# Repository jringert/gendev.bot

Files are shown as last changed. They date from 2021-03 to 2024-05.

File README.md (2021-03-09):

# gendev.bot
Materials for [small rover robot](gendev.bot.esp8266/) used in Generative Development module:
* ESP8266-based [rover robot](gendev.bot.esp8266/) with list of materials and Arduino IDE code
* [Java code running a HTTP server](gendev.bot.runner/) responding base on different engines, e.g., generated code from an UMPLE state machine or a synthezied Spectra controller

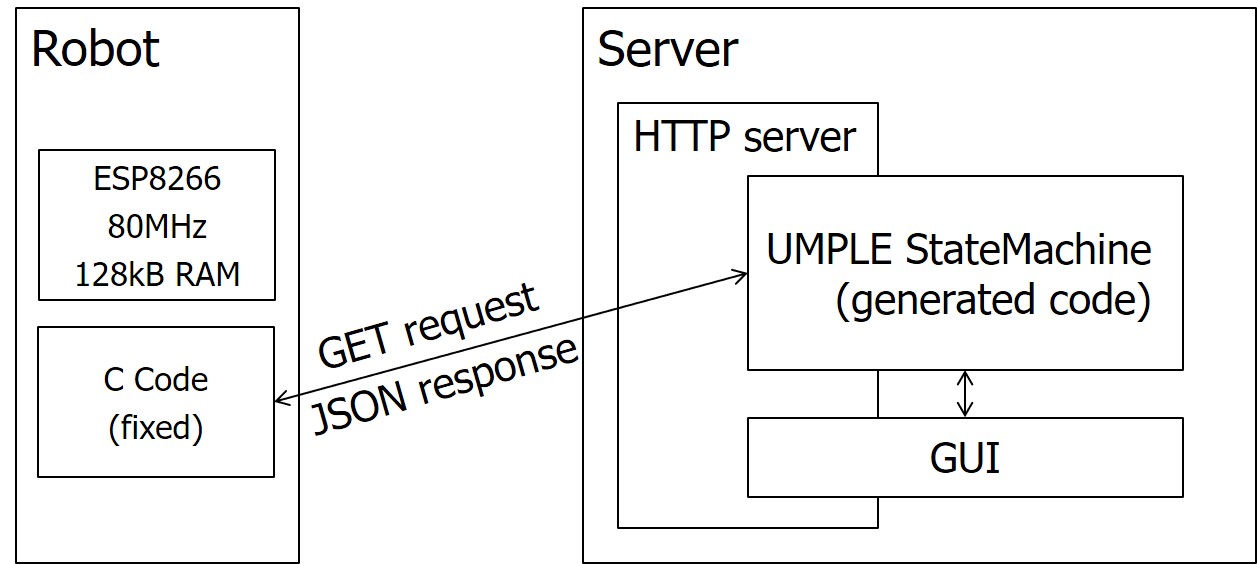
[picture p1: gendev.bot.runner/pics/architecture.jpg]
schematic system overview


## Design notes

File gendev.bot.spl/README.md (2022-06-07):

# gendev.bot.spl
This folder contains variants of the GenDevBot implementation.

* ESP8266-based [rover robot](gendev.bot.esp8266.full/)
* ESP32-based
  * [full featured](gendev.bot.esp32.full/)
  * [full featured but without WiFi manager](gendev.bot.esp32.lean/)
  * [basic USS driving](gendev.bot.esp32.drive/)
  * [basic USS driving with capacitive emergency stop](gendev.bot.esp32.driveEmg/)

An incomplete version of an `#ifdef`-based Software Product Line is contained in [gendev.bot.esp32.all](gendev.bot.esp32.all/). This initial version has been developed [in this video](https://www.youtube.com/watch?v=XeSsomehpjg&list=PLGyeoukah9NYD35EgjpJ6ZT8KZO7JowTK&index=4).

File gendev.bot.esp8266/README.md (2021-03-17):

# gendev.bot.esp8266 Arduino IDE code
Code to flash on the NodeMCU compatible ESP8266.

Requires to install ESP8266 boards in Arduino IDE.
* Select `File > Preferences` under `Additional Boards Manager URLs` add `http://arduino.esp8266.com/stable/package_esp8266com_index.json`
* Select `Tools > Board: ... > Boards manager` type `esp8266` and click `install`

Some computers might require a USB driver to see the ESP8266 in Arduino IDE. See [these instructions](https://learn.sparkfun.com/tutorials/how-to-install-ch340-drivers/all).

Requires the following libraries.
* Select `Tools > Library Manager` and then find these libraries.
  * NewPing by Tim Eckel for ultra-sonic sensor (USS) https://bitbucket.org/teckel12/arduino-new-ping/wiki/Home
  * ArduinoJson by Benoit Blanchon for parsing JSON responses https://arduinojson.org
  * WifiManager by tzapu/tablatronix (a bit far down the list) https://github.com/tzapu/WiFiManager
  
## Functionality
* configures WiFi AP via HTTP
* reads distance using an USS
* sends a HTTP GET request http://host:8080/robot?distance=123
* reads JSON response with fields
  * rightM in {FWD, STP, BWD}
  * leftM in {FWD, STP, BWD}
* powers two or four motors via H-bridge

## Hardware
The links below are [Amazon.co.uk Associate](https://affiliate-program.amazon.co.uk) links. You can use [Amazon Prime Student](https://www.amazon.co.uk/gp/student/signup/info?tag=ringert-21) (free for the first 6 months) to get free one-day shipping.

* [Car with two motors and battery pack](https://amzn.to/3caJQyW) ca. 12GBP
* [ESP8266 as the main controller](https://amzn.to/3v7EAor) ca. 6GBP 
  * or buy 5 of them for 18GBP [5 x ESP8266](https://amzn.to/3emhXGN)
* [Cables with connectors](https://amzn.to/3rInr2J) ca. 7GBP
  * or buy any cheap cable if you are happy do to more soldering
* [L9110S H-bridge to drive motors](https://amzn.to/30t5zge) ca. 5GBP
  * or buy 6 of them for 8GBP [6 x L9110S H-bridge](https://amzn.to/3qvHqQG) (you only need one)
* [HC-SR04 Ultrasonic distance sensor](https://amzn.to/2PNbPNH) ca. 7GBP
  * or buy 5 of them for 10GBP [5 x HC-SR04 sensor](https://amzn.to/3ejJSqZ) (you only need one)
* [AA Batteries](https://amzn.to/38FKIuH) ca. 8GBP (you need 4 to 6)

You can also buy a kit and even save money, e.g., this [Arduino UNO robot](https://amzn.to/3rxuCdJ) for only 33GBP. The problem is that it doesn't have WiFi, but it should be easy to replace the Arduino UNO with an ESP8266 (see list above).

The materials can be bought much cheaper on [Aliexpress](https://aliexpress.com)  if you are willing to wait that long (shipping can take anywhere from a week to a month). You might 20 GBP instead of 40 GBP.

In any case you might need the following tools:
* a soldering iron (to connect the cables to the motors and maybe to the battery pack)
* a small screw driver to connect cables from the motors to the H-bridge
* (optional) a hot glue gun to secure all cables

## Build instructions

A [video of how to connect things](https://youtu.be/WTPfQyEEh8c) is avaiable.

The connections to PINs are documented in the code and shown here. Fritzing files are available in folder docs.
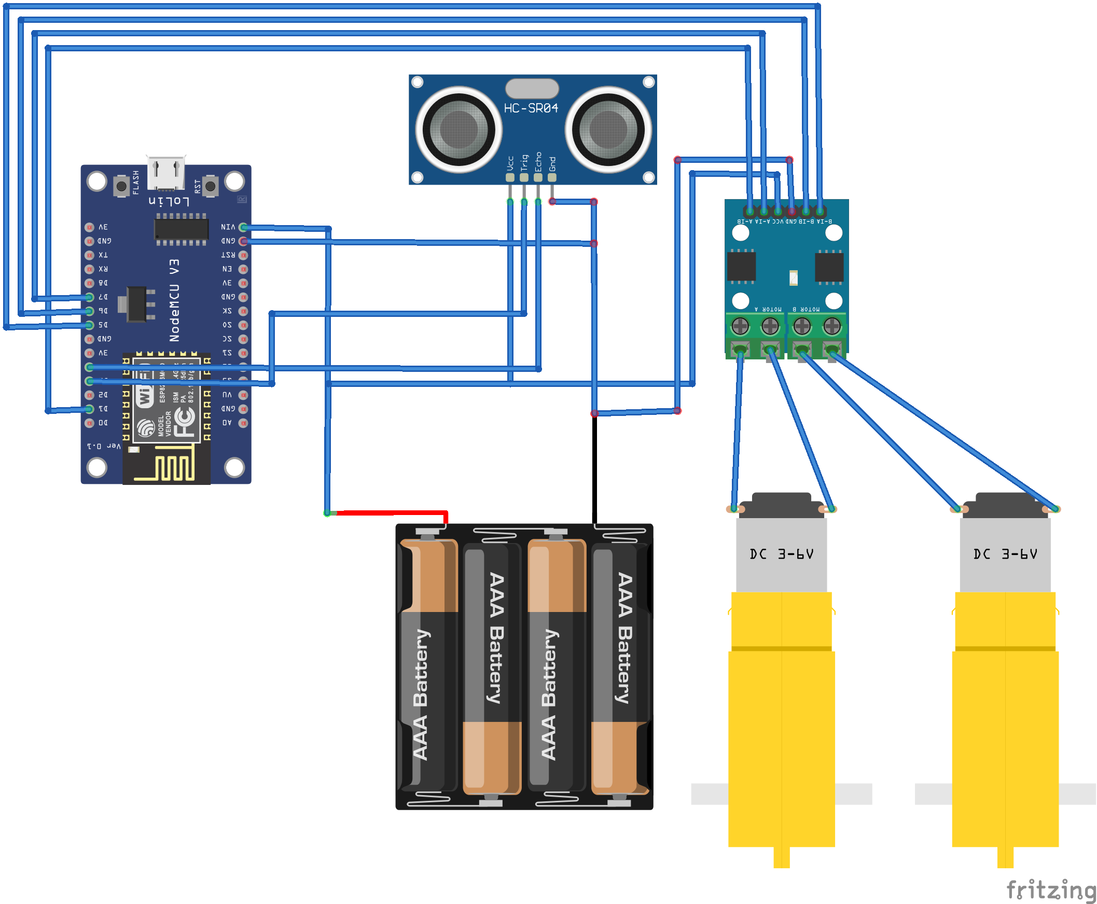
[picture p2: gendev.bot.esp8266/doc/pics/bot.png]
connections ignoring VCC/GND


## Code upload and first run

In the arduino code you have to configure the IP address of the computer that runs the Java program. This requires the ESP8266 and the computer to be on the same network (this is usually the case at home where you have a WiFi router). You might want to configure a fixed IP for the computer in your router settings. Alternatively you can create a mobile hotspot on your phone and connect the computer to it.

Enter the local network IP of the computer (something like 192.168.0.1337) in the line below (ca. line 88 in [gendev.bot.esp8266.ino](gendev.bot.esp8266.ino)). You will also have to enter this IP in the Java code running on the computer.
```c
if (http.begin(client, "192.168.0.1337", 8080, "/robot?distance=" + String(distance), false)) {
```

Once the code is uploaded to the ESP8266 it will create a WiFi network called `GendevBotAP`. Connect to this WiFi, e.g., with your phone or computer and let the ESP8266 scan for networks. Select your network and enter the password. The ESP8266 will then reboot and connect to that network. It will immediately try to talk to the computer running the Java server.

# Possible Hardware Extensions
An easy way to extend the robot is by adding more sesor and additional motors. The ESP8266 should still have a few free pins for that.

Another extension is to put a Raspberry Pi with a camera on the robot to have much more processing power onboard. In this case you can either try to replace the ESP8266 or simply connect it to the Raspberry Pi via WiFi (as in the above setting) or even USB. The Raspberry Pis are much cheaper on [The Pi Hut](https://thepihut.com/) than on Amazon:
* a [Raspberry Pi zero with WiFi](https://thepihut.com/products/raspberry-pi-zero-w) ca. 10GBP, or 
* a [Raspberry Pi 4B](https://thepihut.com/products/raspberry-pi-4-model-b?variant=20064052674622) between 34GBP (2GB RAM) and 74GBP (8GB RAM)
* there are tons of extensions with [cameras](https://thepihut.com/pages/search-results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) etc.

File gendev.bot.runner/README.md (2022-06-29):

# Eclipse project gendev.bot.runner
Project for executing some engine for generated code and making it available for the robot to connect to via HTTP.

Currently supported engines:
* UMPLE StateMaching code (examples included)
* Spectra synthesized controllers
* AspectJ aspects decorating a Java implementation

schematic system overview

## Project contents
* UMPLE StateMachines are in the root of folder src (to generate code from Eclipse)
* Spectra specifications are in the root folder (synthesize controllers from these)
* AspectJ aspects are in in package `gendev.bot.runner.aspectj`

## Plug-Ins
* UMPLE code generation requires the UMPLE plug-in available from `http://cruise.umple.org/org.cruise.umple.eclipse.plugin.update.site`
* Spectra synthesis requires the Spectra Tools plug-in available from `http://smlab.cs.tau.ac.il/syntech/spectra/tools/update/`
* AspectJ ideally via the Eclipse Marketplace or see `https://www.eclipse.org/ajdt/`

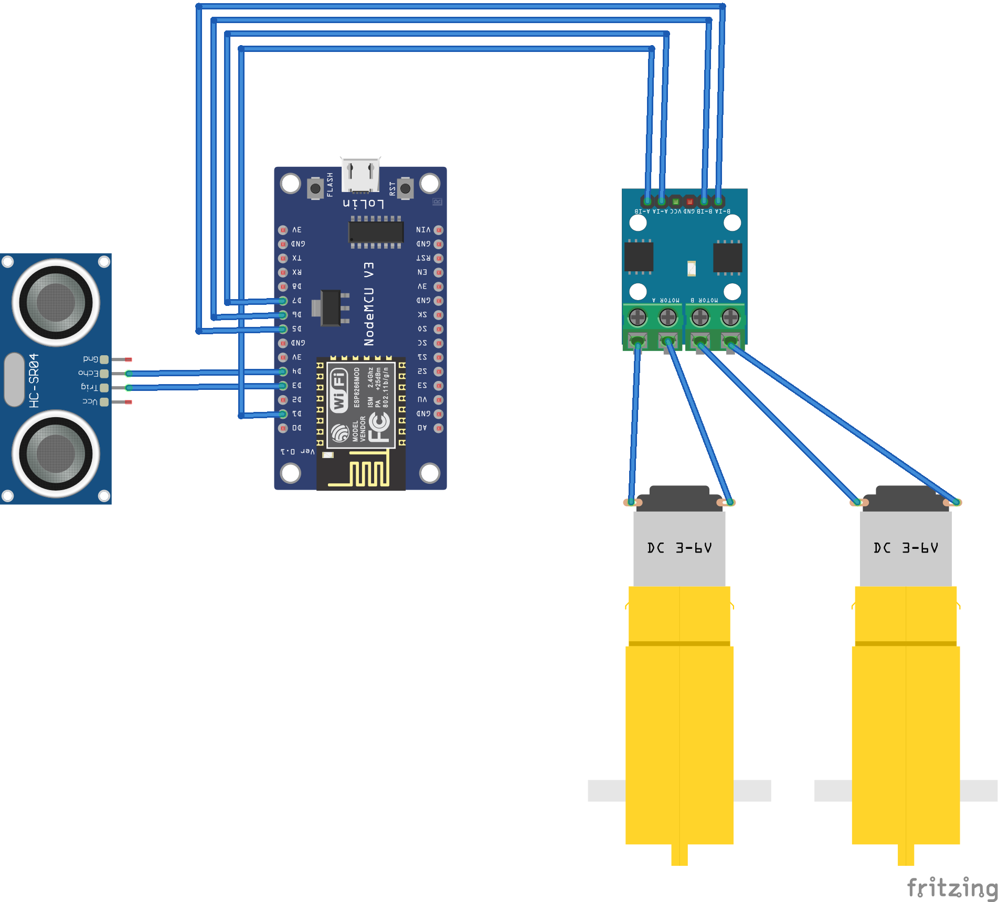
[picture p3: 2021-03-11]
gendev.bot.esp8266/doc/pics/bot_noPower.png

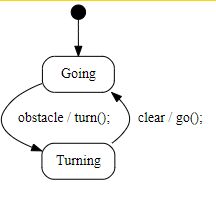
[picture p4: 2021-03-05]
gendev.bot.runner/pics/botV1.jpg

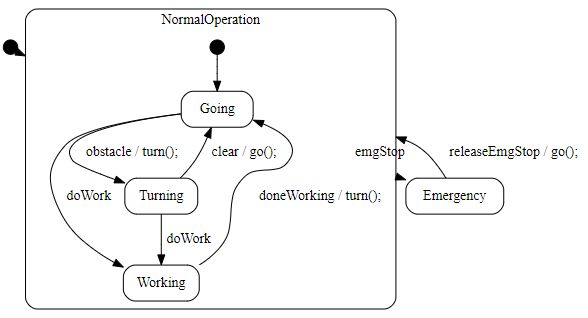
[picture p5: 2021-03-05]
gendev.bot.runner/pics/botV3.jpg

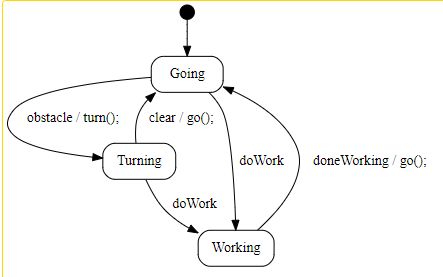
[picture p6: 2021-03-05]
gendev.bot.runner/pics/botV2.jpg

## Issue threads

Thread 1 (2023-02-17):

Simulator for Robot

TibiGG, 2023-02-17:
I was wondering whether there is any tool already made to simulate the behaviour of the robot. Thank you!

jringert, 2023-02-17:
No, we don't have a tool for that, sorry. However, the separation of the execution via a socket- or HTTP-based interface should allow for simulating it in almost any framework (you could even hack one in JavaScript, I guess).

We have reworked the communication part a bit to use sockets instead of HTTP (faster communication for the ESP32/8266). If you are interested in the robot, please let me know, some of the code might be outdated in the repository, e.g., the symbolic controller execution JAR file needs replacing with a later one from the current Spectra version.

TibiGG, 2023-02-17:
Ok, thank you for the quick reply.

Yes, I am interested, and most probably will build the robot. Thank you for letting me know of the outdated jar file. Still, I found that I could run the RobotRunner.java file without any other problem than the connection to a robot, so I will most probably see the issues when I will connect to a real or simulated robot.

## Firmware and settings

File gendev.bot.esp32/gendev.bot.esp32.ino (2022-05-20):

#include <Arduino.h>

#include <ArduinoJson.h> //https://arduinojson.org
#include <WiFiManager.h> //https://github.com/tzapu/WiFiManager

#define USE_MOTORS
#define USE_USS
#define USE_SERIAL


#ifdef USE_MOTORS
#define MOTOR_A_PWM 26 //A-1A
#define MOTOR_A_DIR 27 //A1-B
#define MOTOR_B_PWM 33 //B-1A
#define MOTOR_B_DIR 25 //B-1B
// next one depends a lot on battery power
#define PWM_SLOW 1023 //700  // slow speed PWM duty cycle
// direction of motors -1 BWD, 0 STP, 1 FWD
int dirA = 0;
int dirB = 0;
// time in ms to wait between direction changes
const long waitDirChange = 100;
#endif

#ifdef USE_USS
//See pin problems https://randomnerdtutorials.com/esp8266-pinout-reference-gpios/
#define TRIGGER_PIN  5
#define ECHO_PIN     18
#define MAX_DISTANCE 100 // Maximum distance
#endif



int distance = 0;

unsigned long previousMillis = 0;
// min time between requests in ms
const long interval = 50;

#include <HTTPClient.h>
HTTPClient http;

void setup() {
  #ifdef USE_SERIAL
  Serial.begin(115200);
  #endif

  // create a portal if cannot connect to previous AP
  WiFi.mode(WIFI_STA);
  WiFiManager wm;
  if(!wm.autoConnect("GendevBotAP")) {
    #ifdef USE_SERIAL
    Serial.println("Failed to connect");
    #endif
    ESP.restart();
  } else {
    #ifdef USE_SERIAL
    Serial.println("connected");
    #endif
  }
  http.setReuse(true);

  #ifdef USE_USS
  pinMode(TRIGGER_PIN, OUTPUT);
  pinMode(ECHO_PIN, INPUT);
  #endif
  
  #ifdef USE_MOTORS
  pinMode( MOTOR_B_DIR, OUTPUT );
  pinMode( MOTOR_B_PWM, OUTPUT );
  digitalWrite( MOTOR_B_DIR, LOW );
  digitalWrite( MOTOR_B_PWM, LOW );

  pinMode( MOTOR_A_DIR, OUTPUT );
  pinMode( MOTOR_A_PWM, OUTPUT );
  digitalWrite( MOTOR_A_DIR, LOW );
  digitalWrite( MOTOR_A_PWM, LOW );
  #endif
}

void loop() {
  unsigned long currentMillis = millis();
  if (currentMillis - previousMillis >= interval) {
    previousMillis = currentMillis;
    
    #ifdef USE_USS
    // pulse the USS
    digitalWrite(TRIGGER_PIN, LOW);
    delayMicroseconds(2);
    digitalWrite(TRIGGER_PIN, HIGH);
    delayMicroseconds(10);
    digitalWrite(TRIGGER_PIN, LOW);
    // abort after 6 milliseconds ~ 100cm
    long duration = pulseIn(ECHO_PIN, HIGH, 6000);
    #ifdef USE_SERIAL
    Serial.printf("duration: %ld\n", duration);
    #endif

    if (duration != 0) {
      // roughly cm
      distance = (duration / 58);
    } else {
      distance = MAX_DISTANCE;
    }
    #ifdef USE_SERIAL
    Serial.println(distance);
    #endif
    #endif
      
    // check for WiFi connection
    if (WiFi.status() == WL_CONNECTED) {
      #ifdef USE_SERIAL
      Serial.printf("[HTTP] trying to begin");
      #endif
      if (http.begin("192.168.137.1", 8080, "/robot?distance=" + String(distance))) {
        int httpCode = http.GET();
        if (httpCode > 0) {
          if (httpCode == HTTP_CODE_OK || httpCode == HTTP_CODE_MOVED_PERMANENTLY) {
            String payload = http.getString();
            #ifdef USE_SERIAL
            Serial.println(payload);
            #endif
            StaticJsonDocument<100> doc;
            deserializeJson(doc, payload);
                      
            const char* leftM = doc["leftM"];
            const char* rightM = doc["rightM"];
  
            #ifdef USE_MOTORS
            int dirChange = 0;
            if (strcmp(leftM, "FWD")==0) {
              if (dirA == -1) {
                dirChange++;
              }
              dirA = 1;
            } else if (strcmp(leftM, "BWD")==0) {
              if (dirA == 1) {
                dirChange++;
              }
              dirA = -1;
            } else {
              dirA = 0;
            }
            if (strcmp(rightM, "FWD")==0) {
              if (dirB == -1) {
                dirChange++;
              }
              dirB = 1;
            } else if (strcmp(rightM, "BWD")==0) {
              if (dirB == 1) {
                dirChange++;
              }
              dirB = -1;
            } else {
              dirB = 0;
            }
            // delay of one motor changes direction
            if (dirChange > 0) {
              // important to stop both to avoid asymmetric turns etc.
              stopA();
              stopB();
              delay(dirChange * waitDirChange);
            }
            // issue actual commands
            if (dirA == -1) {
              backA();
            } else if (dirA == 0) {
              stopA();
            } else {
              forwardA();
            }
            if (dirB == -1) {
              backB();
            } else if (dirB == 0) {
              stopB();
            } else {
              forwardB();
            }
            #endif
          }
        } else {
          #ifdef USE_SERIAL
          Serial.printf("[HTTP] GET... failed, error: %s\n", http.errorToString(httpCode).c_str());
          #endif
        }
        http.end();
      } else {
        #ifdef USE_SERIAL
        Serial.printf("[HTTP] Unable to connect\n");
        #endif
      }
    } else {
      #ifdef USE_SERIAL
      Serial.printf("[WiFi] no wifi\n");
      #endif
      #ifdef USE_MOTORS
      stopA();
      stopB();
      #endif
    }
  
  }// millis checker
}

#ifdef USE_MOTORS
void forwardA() {
  digitalWrite( MOTOR_A_DIR, HIGH ); // direction = forward
  analogWrite( MOTOR_A_PWM, 1023-PWM_SLOW ); // PWM speed = slow
}
void forwardB() {
  digitalWrite( MOTOR_B_DIR, HIGH ); // direction = forward
  analogWrite( MOTOR_B_PWM, 1023-PWM_SLOW ); // PWM speed = slow
}

void stopA() {
  digitalWrite( MOTOR_A_DIR, LOW ); // direction = forward
  digitalWrite( MOTOR_A_PWM, LOW ); // PWM speed = slow
}
void stopB() {
  digitalWrite( MOTOR_B_DIR, LOW ); // direction = forward
  digitalWrite( MOTOR_B_PWM, LOW ); // PWM speed = slow
}

void backA() {
  digitalWrite( MOTOR_A_DIR, LOW ); // direction = forward
  analogWrite( MOTOR_A_PWM, PWM_SLOW ); // PWM speed = slow
}
void backB() {
  digitalWrite( MOTOR_B_DIR, LOW ); // direction = forward
  analogWrite( MOTOR_B_PWM, PWM_SLOW ); // PWM speed = slow
}
#endif

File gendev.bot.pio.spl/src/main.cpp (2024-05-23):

// --- CONFIG -------------------------------------------------------------------------------------
//#define STARTUP_DELAY // wait 5 seconds at every startup to connect to serial monitor
#define USE_LAPTOP // use hotspot on laptop as access point
//#define USE_ROUTER // use router as access point
#define TRACE // print debug messages to serial monitor
#define USE_MOTORS // use motors
#define USE_USS // use ultrasonic sensor
#define USE_TOUCH // use touch sensor as emergency stop
#define USE_WIFI // use WiFi to connect to server

// --- INCLUDES -----------------------------------------------------------------------------------
#include <Arduino.h>
#ifdef USE_WIFI
#include <WiFi.h>
#include "TCPRequest.h"
#endif


// --- DEFINES ------------------------------------------------------------------------------------
// See pin problems https://randomnerdtutorials.com/esp8266-pinout-reference-gpios/

#ifdef USE_MOTORS
#define L298N_IN3 26 // A-1A
#define L298N_IN4 27 // A1-B
#define L298N_IN2 25 // B-1A
#define L298N_IN1 33 // B-1B
#endif

#ifdef USE_USS
#define TRIGGER_PIN 5
#define ECHO_PIN 18
#endif
#define MAX_DISTANCE 100 // Maximum distance

#ifdef USE_TOUCH
#define TOUCH_PIN 32
#endif

#define DBG_DELAY 0   // wait $ ms longer for timeouts to debug

#ifdef USE_WIFI
#ifdef USE_LAPTOP
String WIFI_NAME = "jor-lap";
String WIFI_PWD = "********";
String SERVER_IP = "192.168.137.1";
uint16_t SERVER_PORT = 5000;
#endif
#ifdef USE_ROUTER
String WIFI_NAME = "Testing";
String WIFI_PWD = "SE_2022_WLAN";
String SERVER_IP = "192.168.1.247";
uint16_t SERVER_PORT = 5000;
#endif

uint16_t TCP_TIMEOUT = 500;
TCPRequest tcp_conn(SERVER_IP, SERVER_PORT);

// --- FUNCTIONS ----------------------------------------------------------------------------------

void wifi_setup(String wifi_name, String wifi_pwd)
{
  WiFi.mode(WIFI_MODE_STA); // set WiFi to station == client
  WiFi.begin(wifi_name.c_str(), wifi_pwd.c_str());

  #ifdef TRACE
  Serial.print("Connecting WiFi "); 
  #endif

  while (WiFi.status() != WL_CONNECTED)
  {
    #ifdef TRACE
    Serial.print(".");
    #endif
    delay(250);
  }

  #ifdef TRACE
  Serial.print(" done. My IP is ");
  Serial.println(WiFi.localIP().toString());
  #endif
}
#endif

#ifdef USE_MOTORS
void forwardA()
{
  digitalWrite(L298N_IN1, HIGH); // direction = forward
  digitalWrite(L298N_IN2, LOW);  // PWM speed = slow
}

void forwardB()
{
  digitalWrite(L298N_IN3, HIGH); // direction = forward
  digitalWrite(L298N_IN4, LOW);  // PWM speed = slow
}

void stopA()
{
  digitalWrite(L298N_IN1, LOW); // direction = forward
  digitalWrite(L298N_IN2, LOW); // PWM speed = slow
}

void stopB()
{
  digitalWrite(L298N_IN3, LOW); // direction = forward
  digitalWrite(L298N_IN4, LOW); // PWM speed = slow
}

void backA()
{
  digitalWrite(L298N_IN1, LOW);  // direction = forward
  digitalWrite(L298N_IN2, HIGH); // PWM speed = slow
}

void backB()
{
  digitalWrite(L298N_IN3, LOW);  // direction = forward
  digitalWrite(L298N_IN4, HIGH); // PWM speed = slow
}
#endif

int getDistance()
{
  #ifdef USE_USS
  // pulse the USS
  digitalWrite(TRIGGER_PIN, LOW);
  delayMicroseconds(2);
  digitalWrite(TRIGGER_PIN, HIGH);
  delayMicroseconds(10);
  digitalWrite(TRIGGER_PIN, LOW);

  // abort after 6 milliseconds ~ 100cm
  long duration = pulseIn(ECHO_PIN, HIGH, 6000);

  if (duration != 0)
  {
    // roughly cm
    return duration / 58;
  }
  else
  {
  #endif
    return MAX_DISTANCE;
  #ifdef USE_USS
  }
  #endif
}


void setup()
{
  #ifdef STARTUP_DELAY
  delay(5000); // wait 5 seconds for serial monitor
  #endif

  #ifdef TRACE
  Serial.begin(115200);
  #endif

  #ifdef USE_WIFI
  wifi_setup(WIFI_NAME, WIFI_PWD);

  tcp_conn.setTimeout(TCP_TIMEOUT);
  tcp_conn.setTimeout(DBG_DELAY + TCP_TIMEOUT);
  tcp_conn.setReuseConnection(true);
  #endif

  #ifdef USE_USS  
  // set up USS pins
  pinMode(TRIGGER_PIN, OUTPUT);
  pinMode(ECHO_PIN, INPUT);
  #endif

  #ifdef USE_MOTORS
  // set up motor pins
  pinMode(L298N_IN1, OUTPUT);
  pinMode(L298N_IN2, OUTPUT);
  digitalWrite(L298N_IN1, LOW);
  digitalWrite(L298N_IN2, LOW);

  pinMode(L298N_IN3, OUTPUT);
  pinMode(L298N_IN4, OUTPUT);
  digitalWrite(L298N_IN3, LOW);
  digitalWrite(L298N_IN4, LOW);
  #endif
}

void loop()
{
  #ifdef USE_TOUCH
  if (touchRead(TOUCH_PIN) < 20)
  {
    #ifdef USE_MOTORS
    stopA();
    stopB();
    #endif
    delay(100);
    return;
  }
  #endif

  int distance = getDistance();

  #ifdef TRACE
  Serial.printf("DBG::distance = %d\n", distance);
  #endif

  #ifdef USE_WIFI
  tcp_conn.setPayload(String(distance));
  tcp_conn.run();

  if (!tcp_conn.isTimedOut())
  {
    String response = tcp_conn.getResponse();
    #ifdef TRACE
    Serial.println(response);
    #endif

    #ifdef USE_MOTORS
    char leftM = response.charAt(0);
    if (leftM == 'F')
    {
      backB();
    }
    else if (leftM == 'B')
    {
      forwardB();
    }
    else
    {
      stopB();
    }

    char rightM = response.charAt(2);
    if (rightM == 'F')
    {
      forwardA();
    }
    else if (rightM == 'B')
    {
      backA();
    }
    else
    {
      stopA();
    }
    #endif
  }
  else
  {
    #ifdef TRACE
    Serial.printf("DBG::tcp timeout\n");
    #endif

    #ifdef USE_MOTORS
    stopA();
    stopB();
    #endif
  }
  #endif
}

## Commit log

2021-03-05 arduino code for robot
2021-03-11 added connector schematics and building information
    [bot.fzz, bot_noPower.fzz]
2021-03-11 added board manager additional URL
2021-03-12 added info on drivers for ESP
2021-03-14 updated values sent to client (ESP8266) via JSON to only include motor commands
2021-03-17 added printouts for time betwwen requests (ca. 250ms)
2021-03-17 changed PINs to avoid boot and flashing failures (one motor pin and USS pins), added code to delay 100ms or 200ms before extreme changes of motors FWD<->BWD (100ms delay for each side)
    [gendev.bot.esp8266.ino]
2021-03-17 updated sketches of bot to reflect fixed connections
    [bot.fzz, bot_noPower.fzz]
2021-03-17 reverted pins back due to sensor issues
    [bot.fzz, bot_noPower.fzz]
2022-05-20 added ifdefs to remove serial output, replaced NewPing with native code
    [gendev.bot.esp8266.ino]
2022-05-20 variant of robot for ESP32 platform
2023-05-16 fixed sound issue (same as AspectJ solution)
    [AbstractBot.java]
2023-06-13 platform io code of gendevbot for esp32
2024-06-28 code project for platformio to deploy to ESP32 on gendev.bot
